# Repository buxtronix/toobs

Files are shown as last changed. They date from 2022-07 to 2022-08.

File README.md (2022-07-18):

# TOOBS - valve headphone amplifier

A low voltage valve headphone amplifier, based off a simple design
from [Rogers Gomez](https://diyaudioprojects.com/Solid/12AU7-IRF510-LM317-Headamp/).

## Features/specs

- Power: 12vDC <1A
- Frequency response: 15-20kHz +- 2dB
- Input: RCA or 3.5mm stereo, mic passthrough.
- Media control support (via 3.5mm TRRS)
- Output: 3.5mm stereo
- Output protetion: ~5s power-on delay
- BoM cost: ~$45AUD (without 12AU7)

## 3d PCB view

See it [here](https://buxtronix.github.io/toobs/3d/trrs.html). It will take about 20s to load the model.

*(Code from https://github.com/easyw/vrm360)*

## General notes

See more detailed notes on the general circuit on the [original
page](https://diyaudioprojects.com/Solid/12AU7-IRF510-LM317-Headamp/).

### Media control / mic

The board has 4-pin TRRS connectors, and can support media control and mic
passthrough (not supported when using the RCA inputs).

The 'Control' connector near the right RCA jack can be used for media
control. Just connect buttons between G and +, -, P and these will have
the same functionality as inline media controls on many headphones. Don't
forget you also need a 4-pin 3.5mm patch to the input source.

Bridge J4 if your headphones have a 4-pin TRRS connector and you'd like to
bridge the mic and/or media control buttons. You'll also need a TRRS patch
lead on the input.
If your headphones are only 3-pin but you'd like to use the media controls
on the board, remove J4. If you leave J4 bridged with 3 pin headphones,
the media controls will not work.

### Valve bias

During initial testing, you will need to set the valve anode bias. With 
no source playing, adjust ' R. Bias' whilst measuring the Q1 gate voltage,
such that it's about half the supply voltage (~6v). Do the same for 'L bias'
and measuring the gate of Q2. This adjustment would generally only need to
be done once, and perhaps every few dozen hours of operation.

### Balance

The balance control is intended to adjust for any mismatch on the valve
triodes. With a mono source playing, adjust until the audio is centered.

## Photos (rendered)

Assembled board
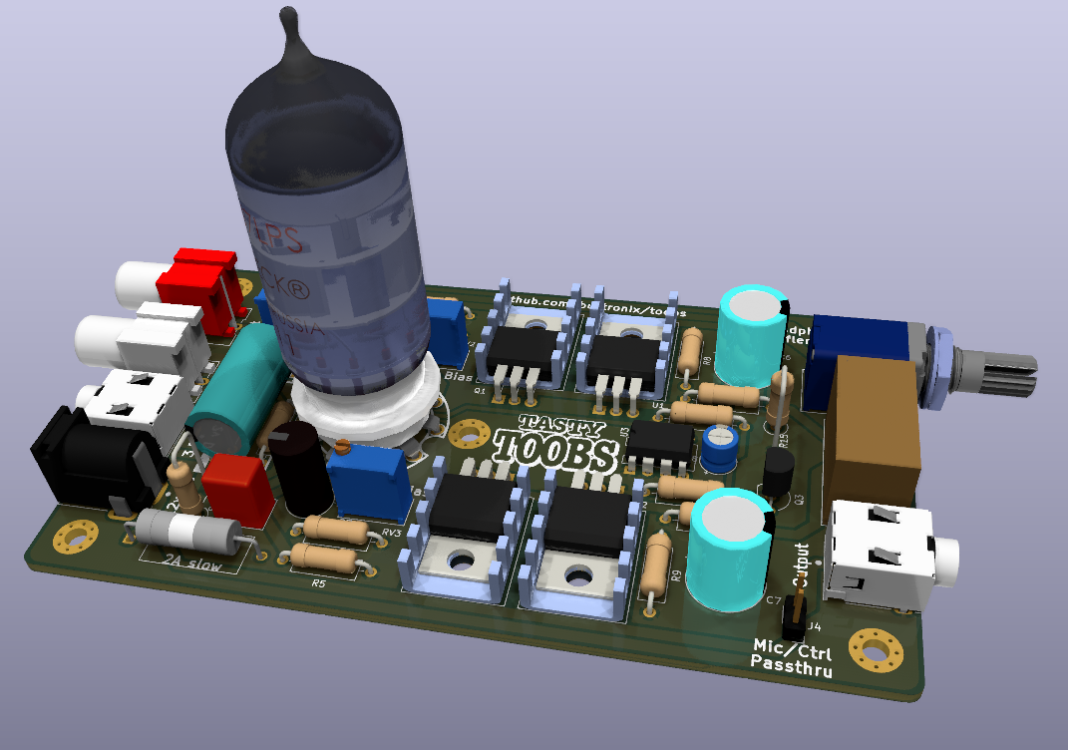
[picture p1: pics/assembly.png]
Board rendering


PCB front side
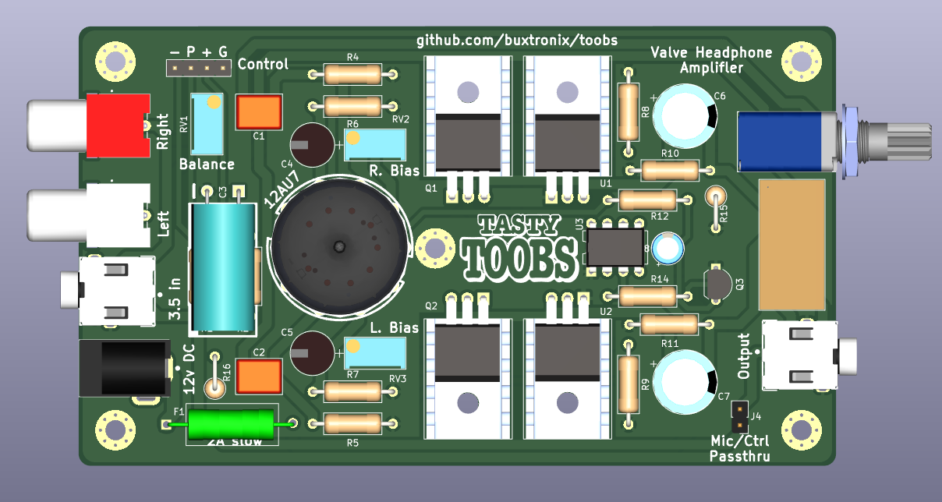
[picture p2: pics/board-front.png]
PCB Front


PCB back side
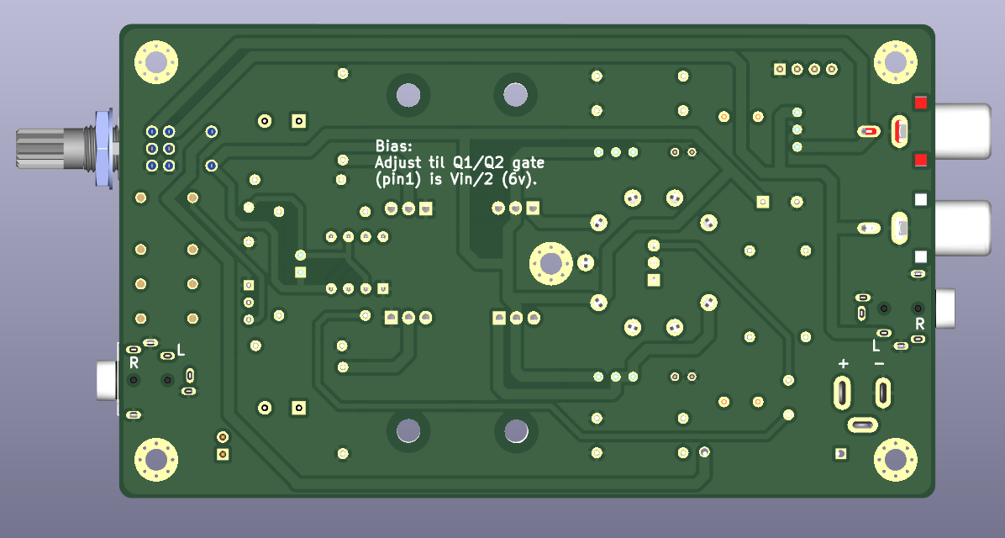
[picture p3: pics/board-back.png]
PCB Back


Schematic
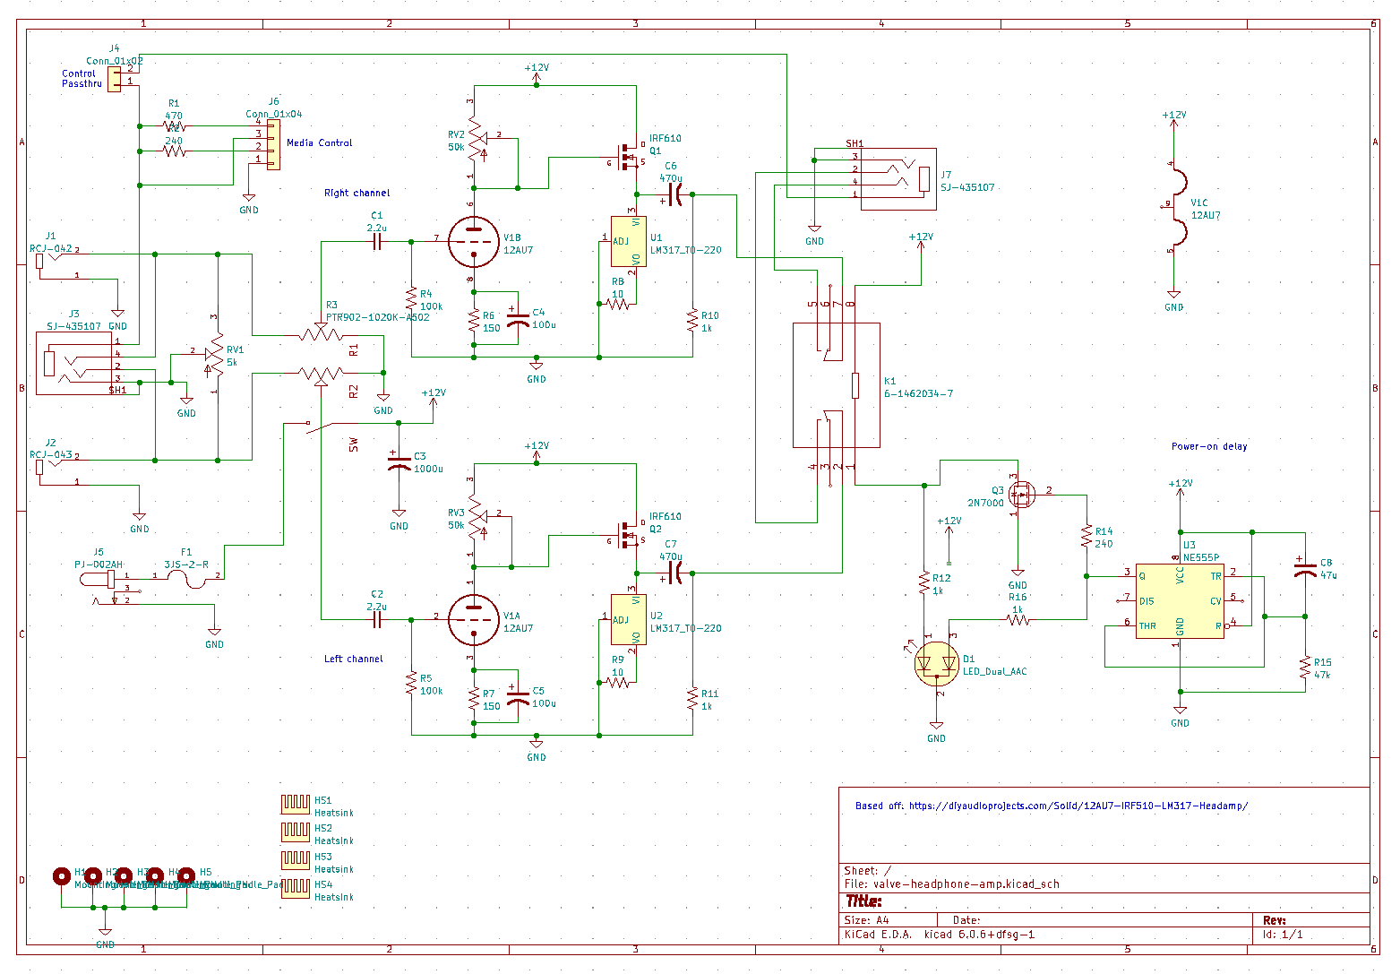
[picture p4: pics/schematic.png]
Schematic


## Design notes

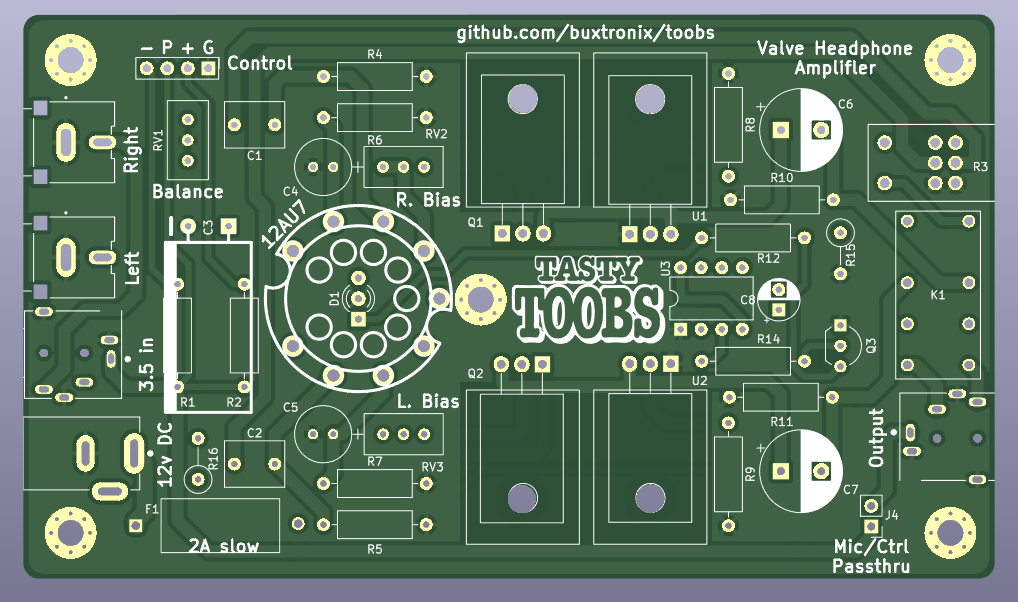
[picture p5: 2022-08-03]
pics/pcb-front.png

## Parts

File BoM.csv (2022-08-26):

Reference(s) | Value | Footprint | PRICE | SUPPLIER_URL
C1 | 2.2u | Capacitor_THT:C_Rect_L7.2mm_W5.5mm_P5.00mm_FKS2_FKP2_MKS2_MKP2 | 1.84 | https://www.digikey.com.au/en/products/detail/kemet/R82CC4220Z370J/4833336
C2 | 2.2u | Capacitor_THT:C_Rect_L7.2mm_W5.5mm_P5.00mm_FKS2_FKP2_MKS2_MKP2 | 1.84 | https://www.digikey.com.au/en/products/detail/kemet/R82CC4220Z370J/4833336
C3 | 1000u | w_capacitors:CP_10x20mm_horiz-L | 1.25 | https://www.digikey.com.au/en/products/detail/rubycon/25ZLS1000MEFC10X20/4977135
C4 | 100u | rubycon:25ZL100MEFCT16.3X11 | 0.49 | https://www.digikey.com.au/en/products/detail/rubycon/25ZL100MEFCT16-3X11/3567835
C5 | 100u | rubycon:25ZL100MEFCT16.3X11 | 0.49 | https://www.digikey.com.au/en/products/detail/rubycon/25ZL100MEFCT16-3X11/3567835
C6 | 470u | Capacitor_THT:CP_Radial_D10.0mm_P5.00mm | 1.04 | https://www.digikey.com.au/en/products/detail/rubycon/25ZLJ470M10X12-5/3134209
C7 | 470u | Capacitor_THT:CP_Radial_D10.0mm_P5.00mm | 1.04 | https://www.digikey.com.au/en/products/detail/rubycon/25ZLJ470M10X12-5/3134209
C8 | 47u | Capacitor_THT:CP_Radial_D5.0mm_P2.50mm | 0.48 | https://www.digikey.com.au/en/products/detail/rubycon/25ZLG47MEFC6-3X7/3563043
D1 | LED_Dual_AAC | LED_THT:LED_D3.0mm-3 | 0.82 | https://www.digikey.com.au/en/products/detail/kingbright/WP115VEGW/3084058
F1 | 3JS-2-R | fuses:3JS 1-R | 0.67 | https://www.digikey.com.au/en/products/detail/bel-fuse-inc/3JS-2-R/1010090
H1 | MountingHole_Pad | MountingHole:MountingHole_3.2mm_M3_Pad_Via
H2 | MountingHole_Pad | MountingHole:MountingHole_3.2mm_M3_Pad_Via
H3 | MountingHole_Pad | MountingHole:MountingHole_3.2mm_M3_Pad_Via
H4 | MountingHole_Pad | MountingHole:MountingHole_3.2mm_M3_Pad_Via
H5 | MountingHole_Pad | MountingHole:MountingHole_3.2mm_M3_Pad_Via
HS1 | Heatsink | heatsink:heatsink_19x13mm | 0.43 | https://www.digikey.com.au/en/products/detail/aavid-thermal-division-of-boyd-corporation/577002B00000G/102507
HS2 | Heatsink | heatsink:heatsink_19x13mm | 0.43 | https://www.digikey.com.au/en/products/detail/aavid-thermal-division-of-boyd-corporation/577002B00000G/102507
HS3 | Heatsink | heatsink:heatsink_19x13mm | 0.43 | https://www.digikey.com.au/en/products/detail/aavid-thermal-division-of-boyd-corporation/577002B00000G/102507
HS4 | Heatsink | heatsink:heatsink_19x13mm | 0.43 | https://www.digikey.com.au/en/products/detail/aavid-thermal-division-of-boyd-corporation/577002B00000G/102507
J1 | RCJ-042 | rca:CUI_RCJ-042 | 2.44 | https://www.digikey.com.au/en/products/detail/cui-devices/RCJ-042/408506
J2 | RCJ-043 | rca:CUI_RCJ-043 | 2.44 | https://www.digikey.com.au/en/products/detail/cui-devices/RCJ-043/408507
J3 | SJ-435107 | 3:CUI_SJ-435107 | 0.98 USD | https://www.digikey.com.au/en/products/detail/cui-devices/SJ-435107/3064634
J4 | Conn_01x02 | Connector_PinHeader_2.54mm:PinHeader_1x02_P2.54mm_Vertical
J5 | PJ-002AH | power:CUI_PJ-002AH | 1.19 | https://www.digikey.com.au/en/products/detail/cui-devices/PJ-002AH/408446
J6 | Conn_01x04 | Connector_PinHeader_2.54mm:PinHeader_1x04_P2.54mm_Vertical
J7 | SJ-435107 | 3:CUI_SJ-435107 | 0.98 USD | https://www.digikey.com.au/en/products/detail/cui-devices/SJ-435107/3064634
K1 | 6-1462034-7 | footprints:PC323-12L-X | 1.90 | https://www.digikey.com.au/en/products/detail/picker-components/PC323-12L-X/12352828
Q1 | IRF610 | Package_TO_SOT_THT:TO-220-3_Horizontal_TabDown | 1.46 | https://www.digikey.com.au/en/products/detail/vishay-siliconix/IRF610PBF-BE3/12396470
Q2 | IRF610 | Package_TO_SOT_THT:TO-220-3_Horizontal_TabDown | 1.46 | https://www.digikey.com.au/en/products/detail/vishay-siliconix/IRF610PBF-BE3/12396470
Q3 | 2N7000 | Package_TO_SOT_THT:TO-92_Inline_Wide | 0.95 | https://www.digikey.com.au/en/products/detail/onsemi/2N7000BU/976604
R1 | 470 | Resistor_THT:R_Axial_DIN0309_L9.0mm_D3.2mm_P12.70mm_Horizontal | 0.32 | https://www.digikey.com.au/en/products/detail/vishay-beyschlag-draloric-bc-components/SFR2500004700FR500/333902
R2 | 240 | Resistor_THT:R_Axial_DIN0309_L9.0mm_D3.2mm_P12.70mm_Horizontal | 0.37 | https://www.digikey.com.au/en/products/detail/vishay-beyschlag-draloric-bc-components/MRS25000C2400FCT00/5064247
R3 | PTR902-1020K-A502 | pot:TRIM_PTR902-1020K-A502 | 6.10 | https://www.digikey.com.au/en/products/detail/bourns-inc/PTR902-2015K-A104/3780813
R4 | 100k | Resistor_THT:R_Axial_DIN0309_L9.0mm_D3.2mm_P12.70mm_Horizontal | 0.64 | https://www.digikey.com.au/en/products/detail/vishay-beyschlag-draloric-bc-components/HVR2500001003FR500/719270
R5 | 100k | Resistor_THT:R_Axial_DIN0309_L9.0mm_D3.2mm_P12.70mm_Horizontal | 0.64 | https://www.digikey.com.au/en/products/detail/vishay-beyschlag-draloric-bc-components/HVR2500001003FR500/719270
R6 | 150 | Resistor_THT:R_Axial_DIN0309_L9.0mm_D3.2mm_P12.70mm_Horizontal | 0.36 | https://www.digikey.com.au/en/products/detail/vishay-beyschlag-draloric-bc-components/SFR2500001500FR500/595677
R7 | 150 | Resistor_THT:R_Axial_DIN0309_L9.0mm_D3.2mm_P12.70mm_Horizontal | 0.36 | https://www.digikey.com.au/en/products/detail/vishay-beyschlag-draloric-bc-components/SFR2500001500FR500/595677
R8 | 10 | Resistor_THT:R_Axial_DIN0309_L9.0mm_D3.2mm_P12.70mm_Horizontal | 0.36 | https://www.digikey.com.au/en/products/detail/vishay-beyschlag-draloric-bc-components/SFR25H0001009FR500/5065713
R9 | 10 | Resistor_THT:R_Axial_DIN0309_L9.0mm_D3.2mm_P12.70mm_Horizontal | 0.36 | https://www.digikey.com.au/en/products/detail/vishay-beyschlag-draloric-bc-components/SFR25H0001009FR500/5065713
R10 | 1k | Resistor_THT:R_Axial_DIN0309_L9.0mm_D3.2mm_P12.70mm_Horizontal | 0.20 | https://www.digikey.com.au/en/products/detail/vishay-beyschlag-draloric-bc-components/SFR2500001001FR500/595699
R11 | 1k | Resistor_THT:R_Axial_DIN0309_L9.0mm_D3.2mm_P12.70mm_Horizontal | 0.20 | https://www.digikey.com.au/en/products/detail/vishay-beyschlag-draloric-bc-components/SFR2500001001FR500/595699
R12 | 1k | Resistor_THT:R_Axial_DIN0309_L9.0mm_D3.2mm_P12.70mm_Horizontal | 0.20 | https://www.digikey.com.au/en/products/detail/vishay-beyschlag-draloric-bc-components/SFR2500001001FR500/595699
R14 | 240 | Resistor_THT:R_Axial_DIN0309_L9.0mm_D3.2mm_P12.70mm_Horizontal | 0.37 | https://www.digikey.com.au/en/products/detail/vishay-beyschlag-draloric-bc-components/MRS25000C2400FCT00/5064247
R15 | 47k | Resistor_THT:R_Axial_DIN0309_L9.0mm_D3.2mm_P5.08mm_Vertical | 0.29 | https://www.digikey.com.au/en/products/detail/vishay-beyschlag-draloric-bc-components/SFR2500004702JA500/5065569
R16 | 1k | Resistor_THT:R_Axial_DIN0309_L9.0mm_D3.2mm_P5.08mm_Vertical | 0.20 | https://www.digikey.com.au/en/products/detail/vishay-beyschlag-draloric-bc-components/SFR2500001001FR500/595699
RV1 | 5k | Potentiometer_THT:Potentiometer_Bourns_3296W_Vertical |  | https://www.ebay.com.au/itm/151504241784
RV2 | 50k | Potentiometer_THT:Potentiometer_Bourns_3296W_Vertical |  | https://www.ebay.com.au/itm/151504157376
RV3 | 50k | Potentiometer_THT:Potentiometer_Bourns_3296W_Vertical |  | https://www.ebay.com.au/itm/151504157376
U1 | LM317_TO-220 | Package_TO_SOT_THT:TO-220-3_Horizontal_TabDown | 1.23 | https://www.digikey.com.au/en/products/detail/onsemi/LM317MABTG/1476820
U2 | LM317_TO-220 | Package_TO_SOT_THT:TO-220-3_Horizontal_TabDown | 1.23 | https://www.digikey.com.au/en/products/detail/onsemi/LM317MABTG/1476820
U3 | NE555P | Package_DIP:DIP-8_W7.62mm | 0.73 | https://www.digikey.com.au/en/products/detail/texas-instruments/NE555P/277057
V1 | 12AU7 | 12au7:socket_gzc9-b |  | https://www.ebay.com.au/itm/314046270418

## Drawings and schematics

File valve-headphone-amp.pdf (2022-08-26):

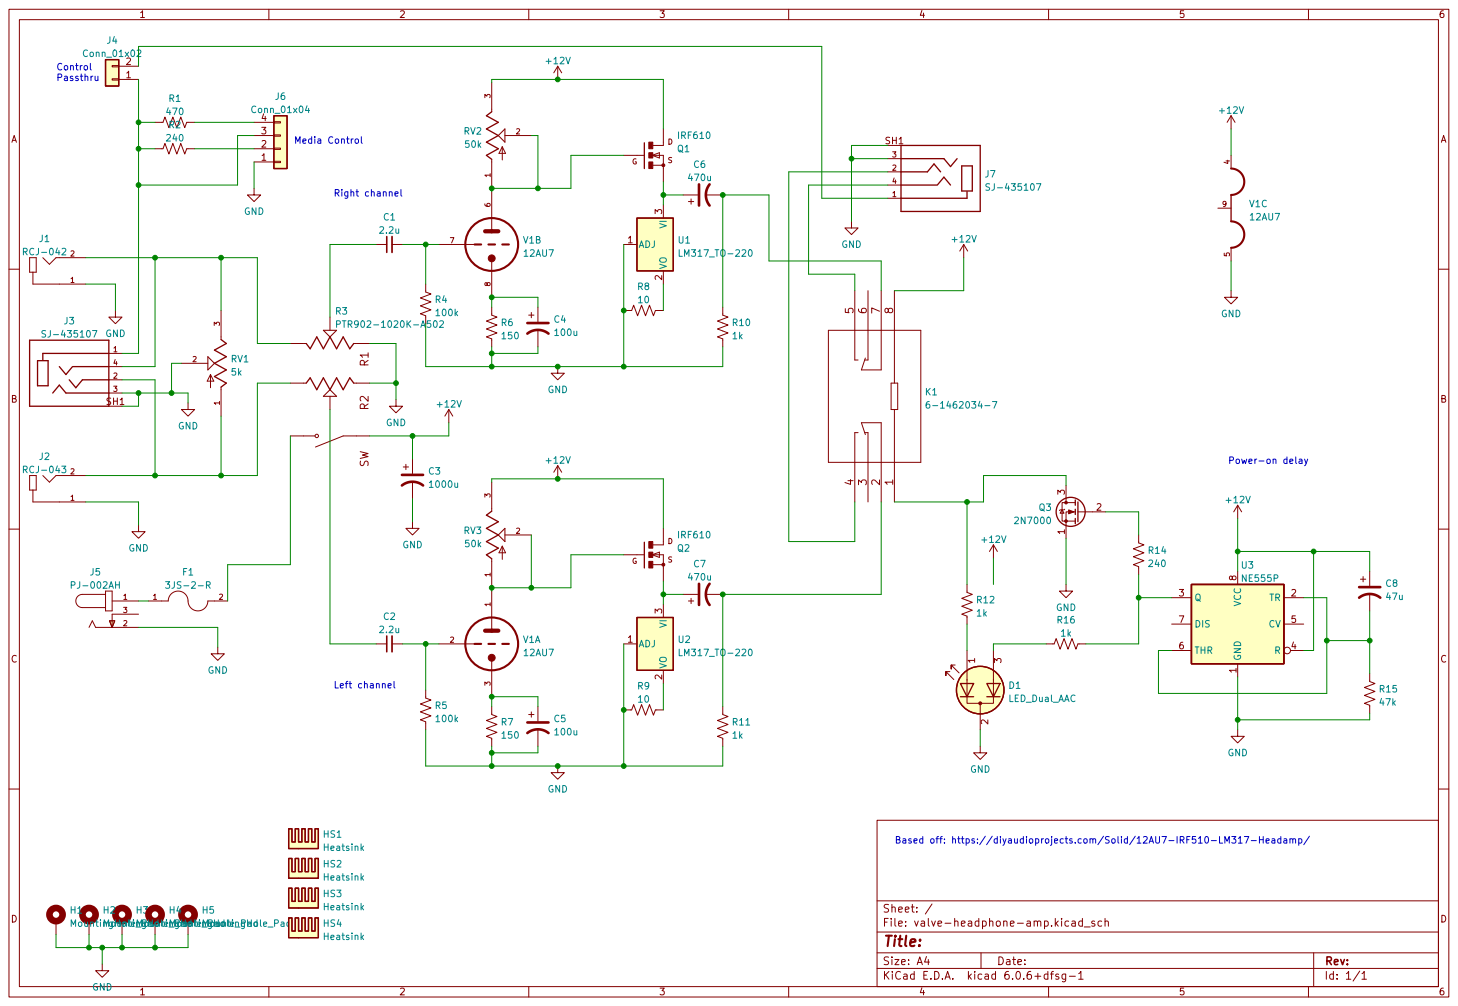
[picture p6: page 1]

Based off: https://diyaudioprojects.com/Solid/12AU7-IRF510-LM317-Headamp/

File: valve-headphone-amp.kicad_sch Sheet: /
Id: 1/1 Title:

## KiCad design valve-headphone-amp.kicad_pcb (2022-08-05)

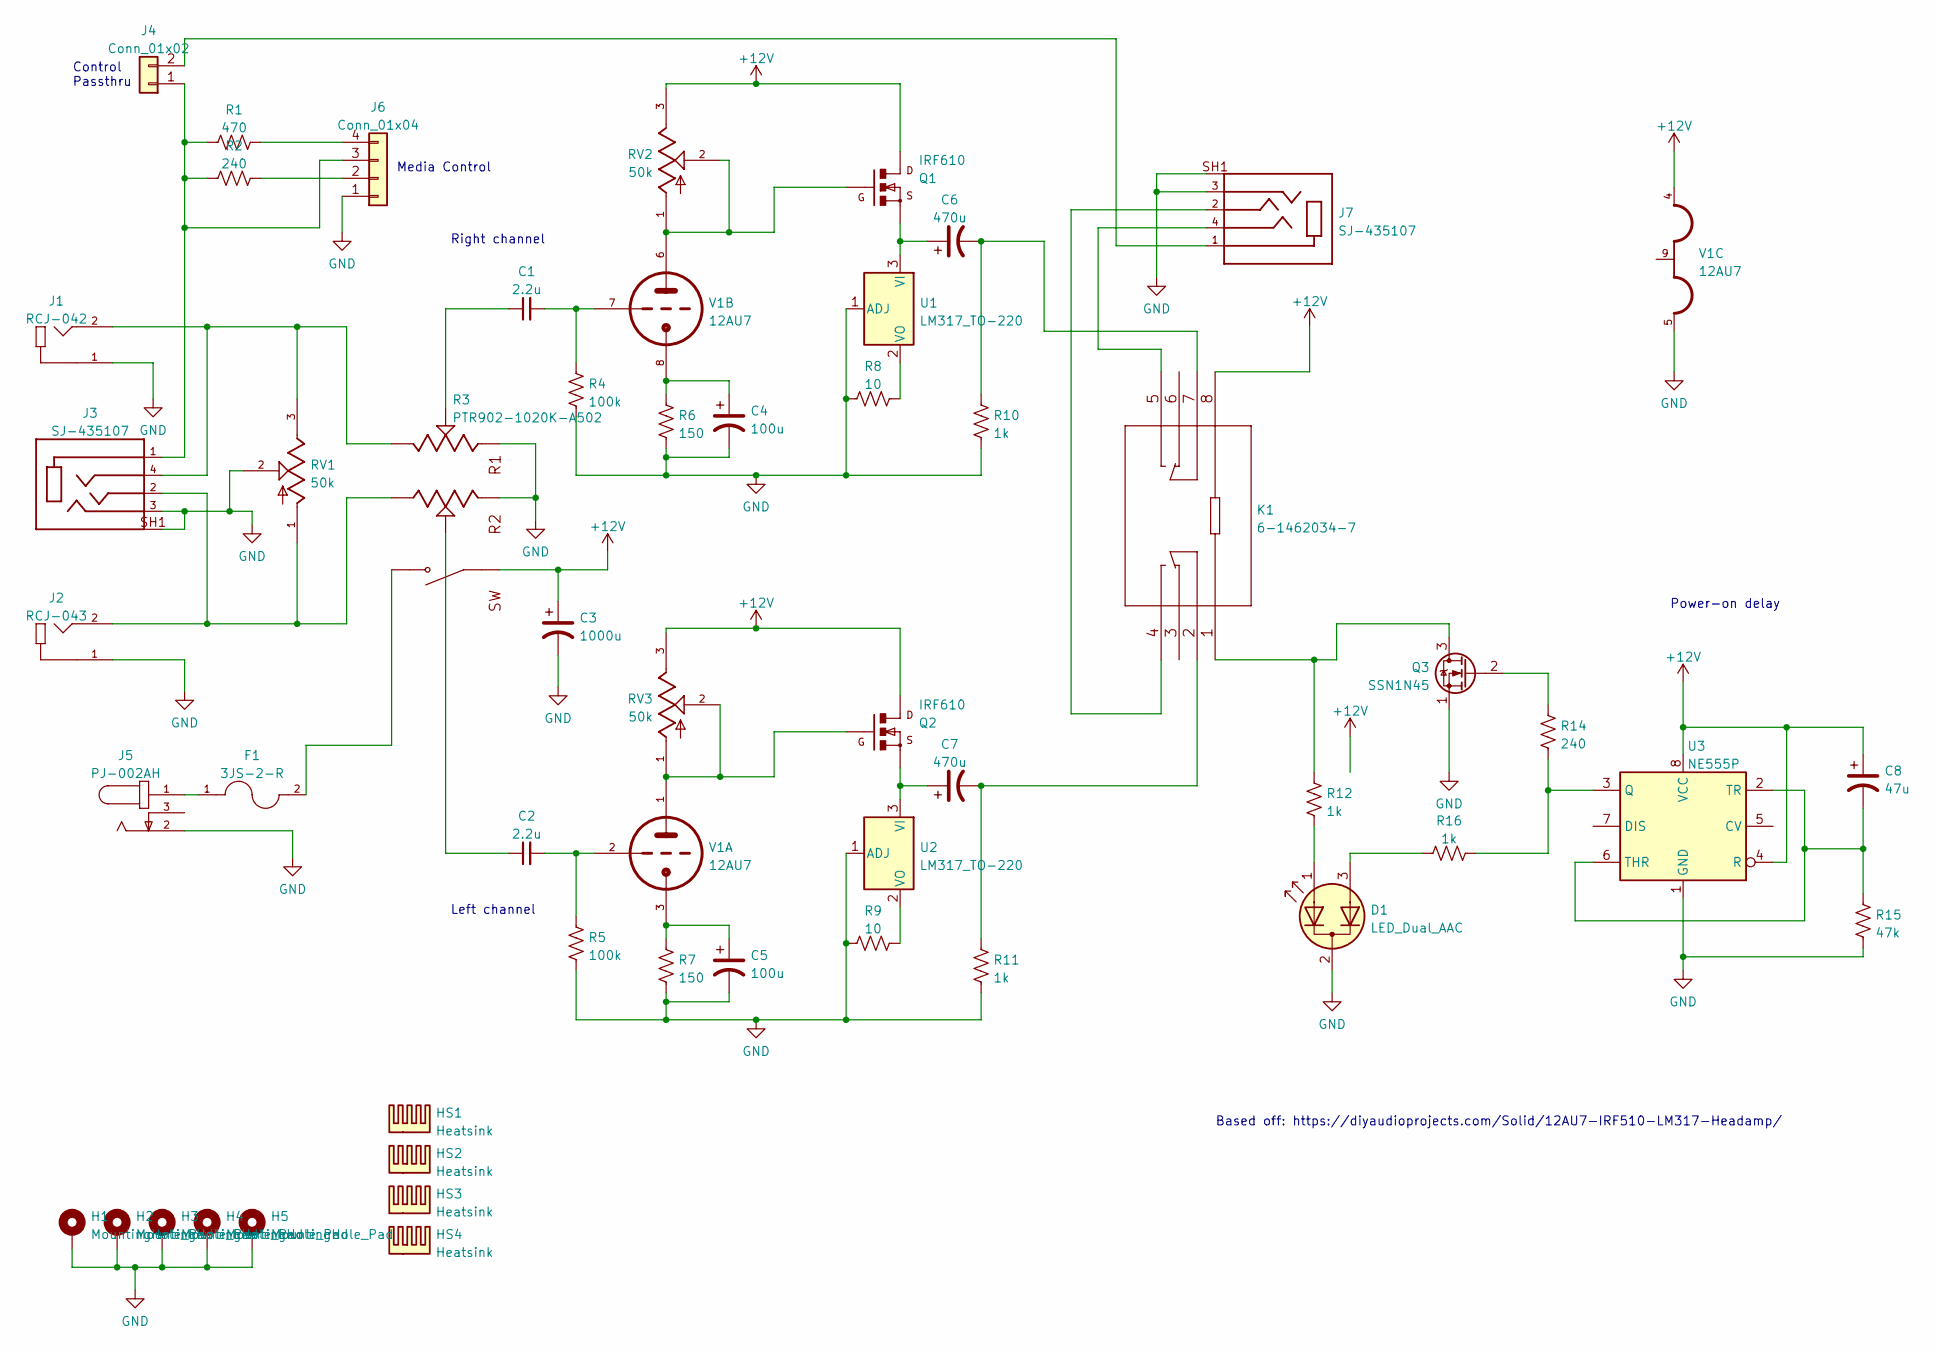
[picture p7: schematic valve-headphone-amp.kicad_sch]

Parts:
C1, C2: 2.2u; C_Rect_L7.2mm_W5.5mm_P5.00mm_FKS2_FKP2_MKS2_MKP2
C3: 1000u; CP_10x20mm_horiz-L
C4, C5: 100u; 25ZL100MEFCT16.3X11
C6, C7: 470u; CP_Radial_D10.0mm_P5.00mm
C8: 47u; CP_Radial_D5.0mm_P2.50mm
D1: LED_Dual_AAC; LED_D3.0mm-3
F1: 3JS-2-R; 3JS 1-R; PARTREV 3SB Dec2019
H1, H2, H3, H4, H5: MountingHole_Pad; MountingHole_3.2mm_M3_Pad_Via
HS1, HS2, HS3, HS4: Heatsink; heatsink_19x13mm
J1: RCJ-042; CUI_RCJ-042
J2: RCJ-043; CUI_RCJ-043
J3, J7: SJ-435107; CUI_SJ-435107
J4: Conn_01x02; PinHeader_1x02_P2.54mm_Vertical
J5: PJ-002AH; CUI_PJ-002AH
J6: Conn_01x04; PinHeader_1x04_P2.54mm_Vertical
K1: 6-1462034-7; PC323-12L-X
Q1, Q2: IRF610; TO-220-3_Horizontal_TabDown
Q3: SSN1N45; TO-92_Inline_Wide
R1: 470; R_Axial_DIN0309_L9.0mm_D3.2mm_P12.70mm_Horizontal
R2, R14: 240; R_Axial_DIN0309_L9.0mm_D3.2mm_P12.70mm_Horizontal
R3: PTR902-1020K-A502; TRIM_PTR902-1020K-A502; PARTREV 10/19
R4, R5: 100k; R_Axial_DIN0309_L9.0mm_D3.2mm_P12.70mm_Horizontal
R6, R7: 150; R_Axial_DIN0309_L9.0mm_D3.2mm_P12.70mm_Horizontal
R8, R9: 10; R_Axial_DIN0309_L9.0mm_D3.2mm_P12.70mm_Horizontal
R10, R11, R12: 1k; R_Axial_DIN0309_L9.0mm_D3.2mm_P12.70mm_Horizontal
R15: 47k; R_Axial_DIN0309_L9.0mm_D3.2mm_P5.08mm_Vertical
R16: 1k; R_Axial_DIN0309_L9.0mm_D3.2mm_P5.08mm_Vertical
RV1, RV2, RV3: 50k; Potentiometer_Bourns_3296W_Vertical; PARTREV 08/26/10
U1, U2: LM317_TO-220; TO-220-3_Horizontal_TabDown
U3: NE555P; DIP-8_W7.62mm
V1: 12AU7; socket_gzc9-b

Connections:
+12V: C3.1, C8.1, K1.8, Q1.2, Q2.2, R3.COM, RV2.3, RV3.3, U3.4 (R), U3.8 (VCC), V1.4
GND: C3.2, C4.2, C5.2, D1.2 (K), H1.1, H2.1, H3.1, H4.1, H5.1, J1.1, J2.1, J3.3, J3.SH1 (Shield), J5.2, J6.1, J7.3, J7.SH1 (Shield), Q3.1 (S), R3.R1_1, R3.R2_1, R4.2, R5.2, R6.2, R7.2, R8.1, R9.1, R10.1, R11.1, R15.2, RV1.2, U1.1 (ADJ), U2.1 (ADJ), U3.1 (GND), V1.5
unnamed: C1.1, R3.R1_2
unnamed: C1.2, R4.1, V1.7
unnamed: C2.1, R3.R2_2
unnamed: C2.2, R5.1, V1.2
unnamed: C4.1, R6.1, V1.8
unnamed: C5.1, R7.1, V1.3
unnamed: C6.1, Q1.3, U1.3 (VI)
unnamed: C6.2, K1.7, R10.2
unnamed: C7.1, Q2.3, U2.3 (VI)
unnamed: C7.2, K1.2, R11.2
unnamed: C8.2, R15.1, U3.2 (TR), U3.6 (THR)
unnamed: D1.1 (A1), R12.1
unnamed: F1.1, J5.1
unnamed: F1.2, R3.NO
unnamed: J1.2, J3.4, R3.R1_3, RV1.3
unnamed: J2.2, J3.2, R3.R2_3, RV1.1
unnamed: J3.1, J4.1, J6.3, R1.2, R2.2
unnamed: J4.2, J7.1
unnamed: J6.2, R2.1
unnamed: J6.4, R1.1
unnamed: J7.2, K1.4
unnamed: J7.4, K1.5
unnamed: K1.1, Q3.3 (D), R12.2
unnamed: Q1.1, RV2.1, RV2.2, V1.6
unnamed: Q2.1, RV3.1, RV3.2, V1.1
unnamed: Q3.2 (G), R14.2
unnamed: R8.2, U1.2 (VO)
unnamed: R9.2, U2.2 (VO)
unnamed: R14.1, R16.1, U3.3 (Q)
unnamed: D1.3 (A2), R16.2

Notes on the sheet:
Right channel
Control Passthru
Left channel
Based off: https://diyaudioprojects.com/Solid/12AU7-IRF510-LM317-Headamp/
Media Control
Power-on delay

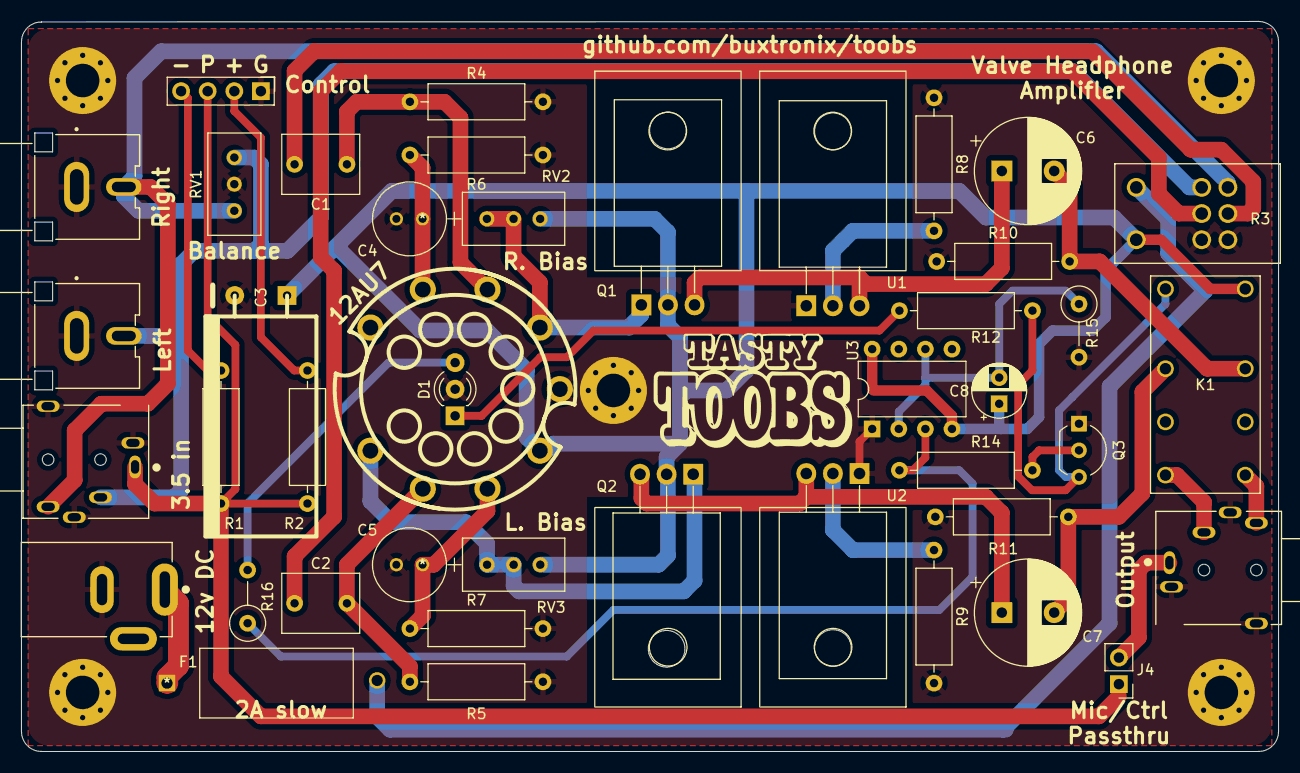
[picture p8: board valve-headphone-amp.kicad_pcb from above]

Board: 2 copper layers, 120.0 x 69.7 mm, 52 parts (0 on the bottom side), 32 nets.

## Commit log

2022-06-29 TOOBS - initial checkin
    [valve-headphone-amp.kicad_pcb, valve-headphone-amp.kicad_sch]
2022-06-29 Add BoM
    [BoM.csv]
2022-07-15 Version with TRRS and media button support
    [valve-headphone-amp.kicad_pcb, valve-headphone-amp.kicad_sch]
2022-07-15 Add schematic pdf
2022-07-16 Add media
    [valve-headphone-amp.kicad_pcb]
2022-07-18 updates, bom
    [BoM.csv, valve-headphone-amp.kicad_sch]
2022-07-22 Add LED for glow
    [BoM.csv, valve-headphone-amp.kicad_pcb, valve-headphone-amp.kicad_sch]
2022-08-03 update a bit more
    [BoM.csv, valve-headphone-amp.kicad_pcb, valve-headphone-amp.kicad_sch]
2022-08-05 pcb fab updates
    [valve-headphone-amp.kicad_pcb]
2022-08-26 update parts
    [BoM.csv, valve-headphone-amp.kicad_sch]
2022-08-26 update schematic export

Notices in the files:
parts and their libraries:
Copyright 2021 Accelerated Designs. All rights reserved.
